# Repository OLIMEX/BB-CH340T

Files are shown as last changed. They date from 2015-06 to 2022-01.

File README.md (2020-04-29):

# BB-CH340T

OSHW USB to serial converter with CH340

The board and schematic files are created with KiCad.

Product page: https://www.olimex.com/Products/Breadboarding/BB-CH340T/open-source-hardware

## Licensee
* Hardware is released under CERN Open Hardware Licence Version 2 -
Strongly Reciprocal
* Software is released under GPL3 Licensee
* Documentation is released under CC BY-SA 3.0

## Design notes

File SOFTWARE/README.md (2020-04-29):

# Software setup for BB-CH340T

Old Linux driver has bug with PLL settings not allowing CH340T to work over 115200 bps.

This is fixed in Linux Kernel 5.5 and up, but if you have Linux with old kernels you can fix this by following: 

https://github.com/OLIMEX/ch340-dkms

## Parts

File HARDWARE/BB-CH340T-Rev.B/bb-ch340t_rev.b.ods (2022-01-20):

Designation | Quantity | Designator | Package
SMD ИС CH340T SSOP20 | 1 | U1 | SSOP-20W
SMD РЕЗ 0603 1 K 5% | 1 | R1 | R_0603_5MIL_DWS
HR1X4 | 1 | POUT1 | HN1x4
SMD СЪЕДИНИТЕЛ MISB-SWMM-5B-LF | 1 | USB1 | USB-MICRO_MISB-SWMM-5B_LF
SMD КОНД 0603 2.2 UF X5R 6.3VDC 10% | 1 | C1 | C_0603_5MIL_DWS
SMD КОНД 0603 10 NF X7R 50VDC 10% | 1 | C3 | C_0603_5MIL_DWS
SMD КОНД 0603 39 PF C0G 5% | 2 | C4,C5 | C_0603_5MIL_DWS
SMD РЕЗОНАТОР КВАРЦ - HU49S 12 MHZ 20ppm 20pf | 1 | Y1 | Q_49U3HMS
SMD ДИОД 1N5819 (S4 SOD-123) | 1 | D1 | SOD-123_KA

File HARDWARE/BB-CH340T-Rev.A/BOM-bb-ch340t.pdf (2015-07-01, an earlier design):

bb-ch340t
Id | Designator | Package | Quantity | Designation
1 | U1 | SSOP-20W | 1 | CH340H/T
2 | C1 | C_0603 | 1 | 2.2uF
3 | C2 | C_0603 | 1 | 100nF
4 | C3 | C_0603 | 1 | 10nF
5 | C4,C5 | C_0603 | 2 | 22p
6 | | Pin_Header_Angled_1x04 | 1 | HR1x4
12 | USB1 | USB_Mini-B | 1 | USB-MINI-B
13 | Y1 | Q_49U3HMS | 1 | 12.0MHz

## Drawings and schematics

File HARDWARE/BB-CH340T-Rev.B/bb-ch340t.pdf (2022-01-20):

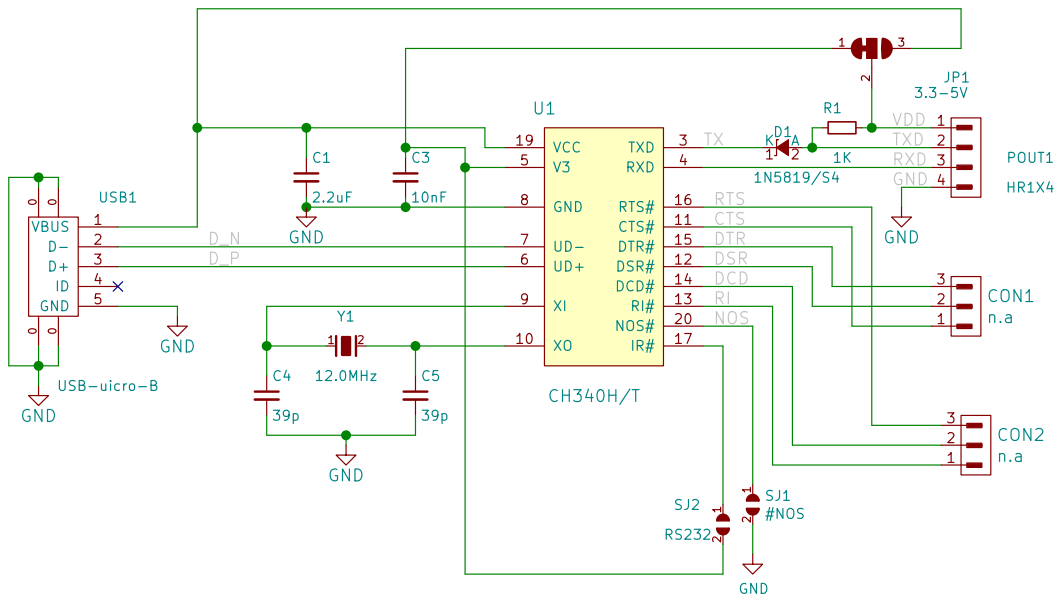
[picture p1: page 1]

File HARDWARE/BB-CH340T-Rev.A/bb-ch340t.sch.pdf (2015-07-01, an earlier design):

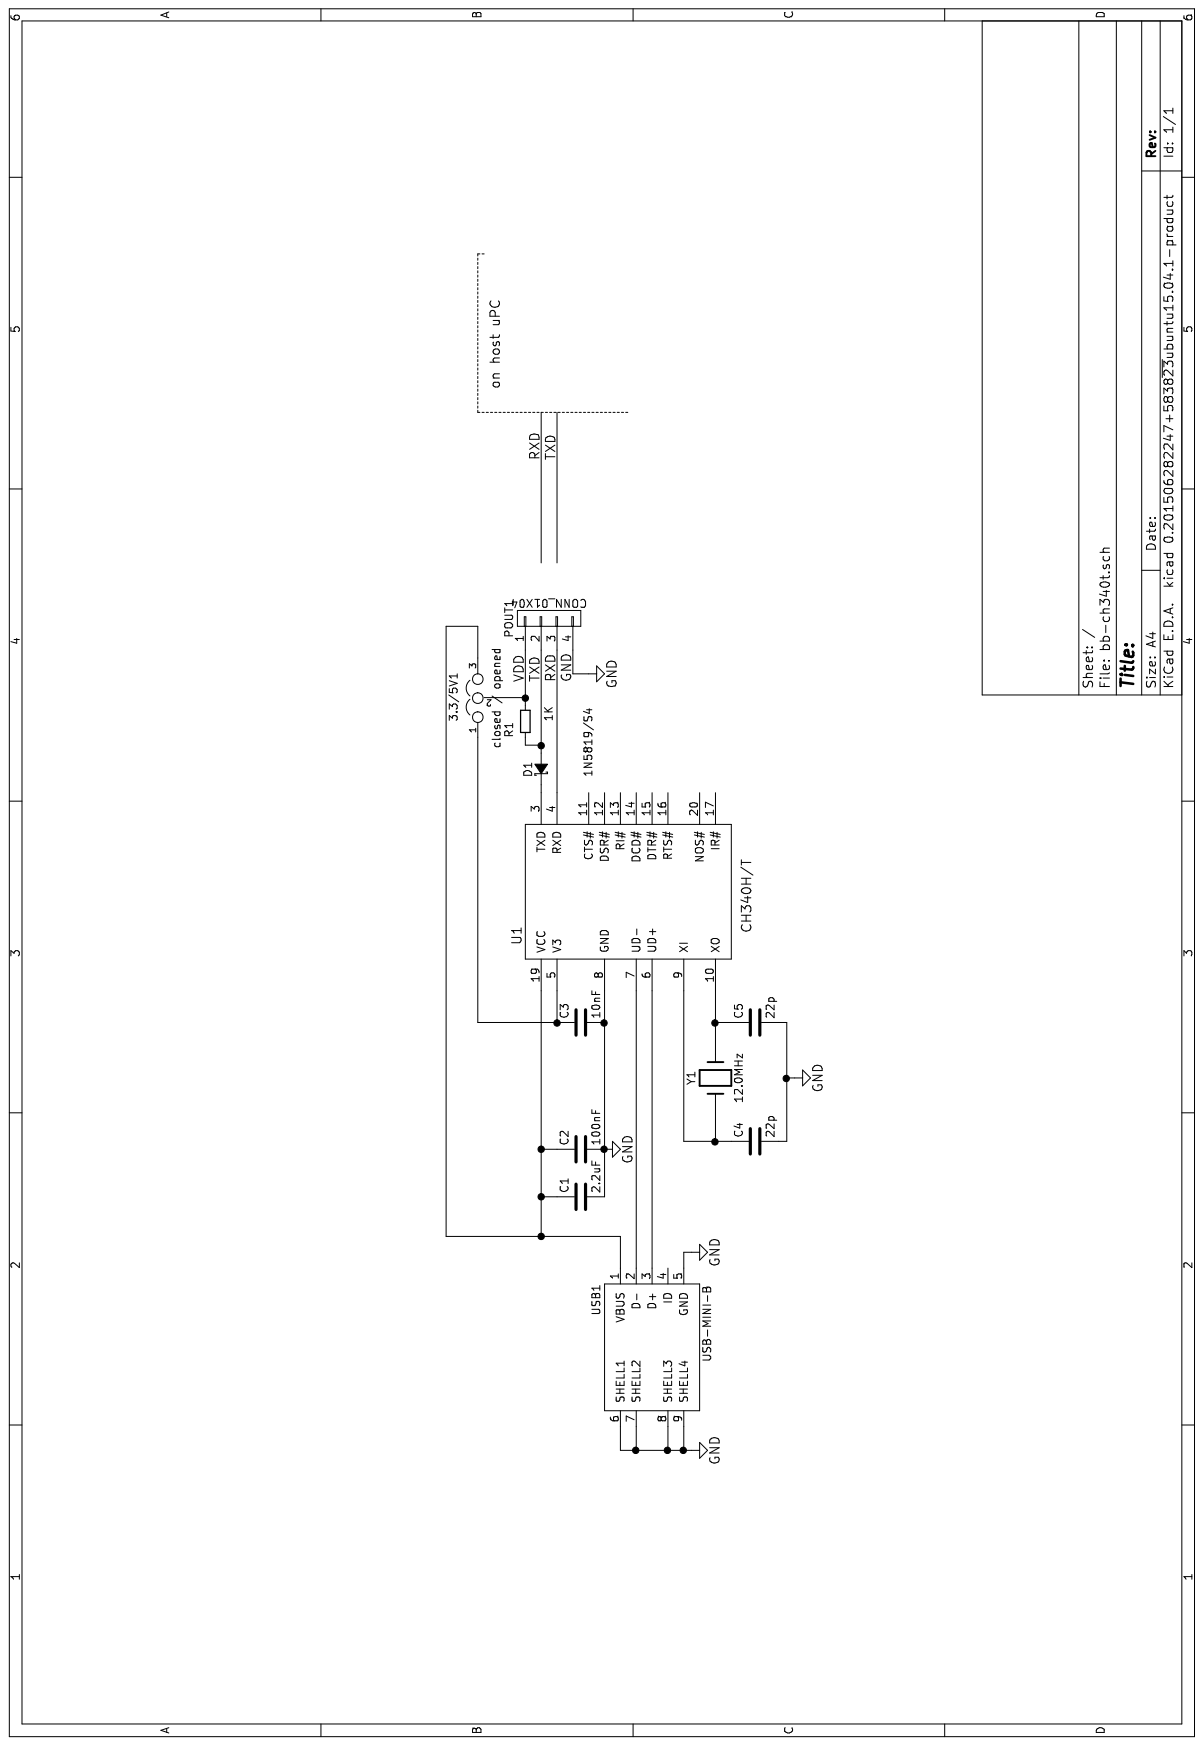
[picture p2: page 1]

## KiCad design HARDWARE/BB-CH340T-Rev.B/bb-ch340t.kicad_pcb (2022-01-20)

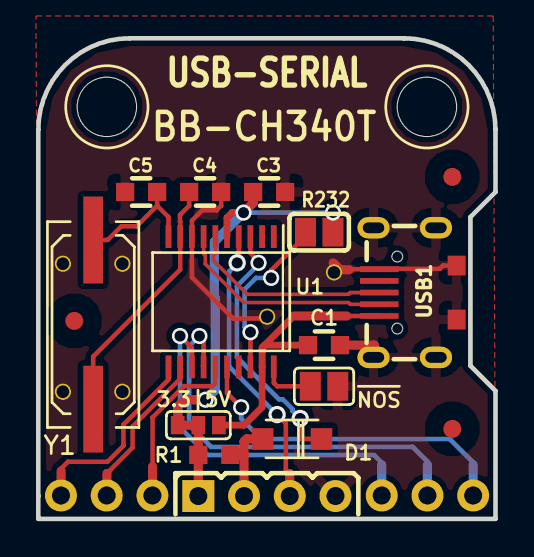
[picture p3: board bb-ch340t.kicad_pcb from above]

Board: 2 copper layers, 25.4 x 26.7 mm, 21 parts (0 on the bottom side), 19 nets.

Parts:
C1: 2.2uF; C_0603_5MIL_DWS
C3: 10nF; C_0603_5MIL_DWS
C4, C5: 39p; C_0603_5MIL_DWS
CON1, CON2: n.a; HN1x3
D1: 1N5819/S4; SOD-123_KA
JP1: 3.3-5V; SJ_2_SMALL_12_TIED
POUT1: HR1X4; HN1x4
R1: 1K; R_0603_5MIL_DWS
Ref**: Val**; via_09_07
Ref**#2, Ref**#3, Ref**#4, Ref**#5, Ref**#6: Val**; via_09_07
SJ1: #NOS; SJ
SJ2: RS232; SJ
U1: CH340H/T; SSOP-20W
USB1: USB-uicro-B; USB-MICRO_MISB-SWMM-5B_LF
Y1: 12.0MHz; Q_49U3HMS

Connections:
/CTS: CON1.1, U1.11
/DCD: CON2.2, U1.14
/DSR: CON1.2, U1.12
/DTR: CON1.3, U1.15
/D_N: U1.7, USB1.2
/D_P: U1.6, USB1.3
/NOS: SJ1.1, U1.20
/RI: CON2.1, U1.13
/RTS: CON2.3, U1.16
/RXD: POUT1.3, U1.4
/TX: D1.1, U1.3
/TXD: D1.2, POUT1.2, R1.2
/VDD: JP1.2, POUT1.1, R1.1
GND: C1.2, C3.2, C4.2, C5.2, POUT1.4, Ref**.0, Ref**#2.0, Ref**#3.0, Ref**#4.0, Ref**#5.0, Ref**#6.0, SJ1.2, U1.8, USB1.0, USB1.5
unnamed: C1.1, JP1.3, U1.19, USB1.1
unnamed: C3.1, JP1.1, SJ2.2, U1.5
unnamed: C4.1, U1.9, Y1.1
unnamed: C5.1, U1.10, Y1.2
unnamed: SJ2.1, U1.18

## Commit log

2015-06-26 upload CAD files
    [bb-ch340t-B_Cu.gbr, bb-ch340t-B_Mask.gbr, bb-ch340t-B_SilkS.gbr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]
2015-07-01 Schematic update
    [bb-ch340t.sch]
2020-04-29 fix structure
    [bb-ch340t-2020-04-29-09-36-51.sch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]
2022-01-20 Update
    revision B
    [bb-ch340t.kicad_pcb, bb-ch340t.sch, bb-ch340t_rev.b.ods]

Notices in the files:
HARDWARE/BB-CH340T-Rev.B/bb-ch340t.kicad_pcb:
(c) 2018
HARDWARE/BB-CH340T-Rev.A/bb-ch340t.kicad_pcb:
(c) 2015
